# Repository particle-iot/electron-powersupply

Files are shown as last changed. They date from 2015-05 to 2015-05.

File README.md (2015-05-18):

Electron Power Management
---
[Place to host the experimental power supply design files for the Electron]

> To put it simply, the challenge in designing the power supply unit for the Electron is _supply and demand_. 

A cellular module is a power hungry device. Unlike WiFi, a GSM module requires a higher burst of power during transmission. These power/current spikes can go as high as 2Amps. This clearly exceeds USB's limit of 500mA in most cases. When developing on the Electron connected to a computer, care must be taken not to exceed the USB's limit while maintaining uninterrupted power to the cellular module. Most portable devices overcome this by having a battery connected at all times, like mobile phones. For a device like the Electron, it becomes essential to have the flexibility to power it either via the USB, battery or both.

The USB powered GSM modems currently available in the market use a switch-mode DC regulator with a high capacity bulk capacitor at the output. This capacitor stores enough energy to power the GSM module during its peak power requirements. At the same time, the regulator makes sure not to exceed the 500mA limit of draw current from a USB port. Most of the USB ports on today's computers are capable of sourcing 1Amp of continuous current. This allows for the use of a smaller bulk capacitor, but you still need to use one.

Things get a little interesting when you consider that 2G and 3G power requirements are completely different. The main difference is that a 2G TX burst will consume upto 2Amp of peak current, while in 3G burst is more controllable and flat with a peak requirement of 0.8A.

**Potential setup for the power unit:**

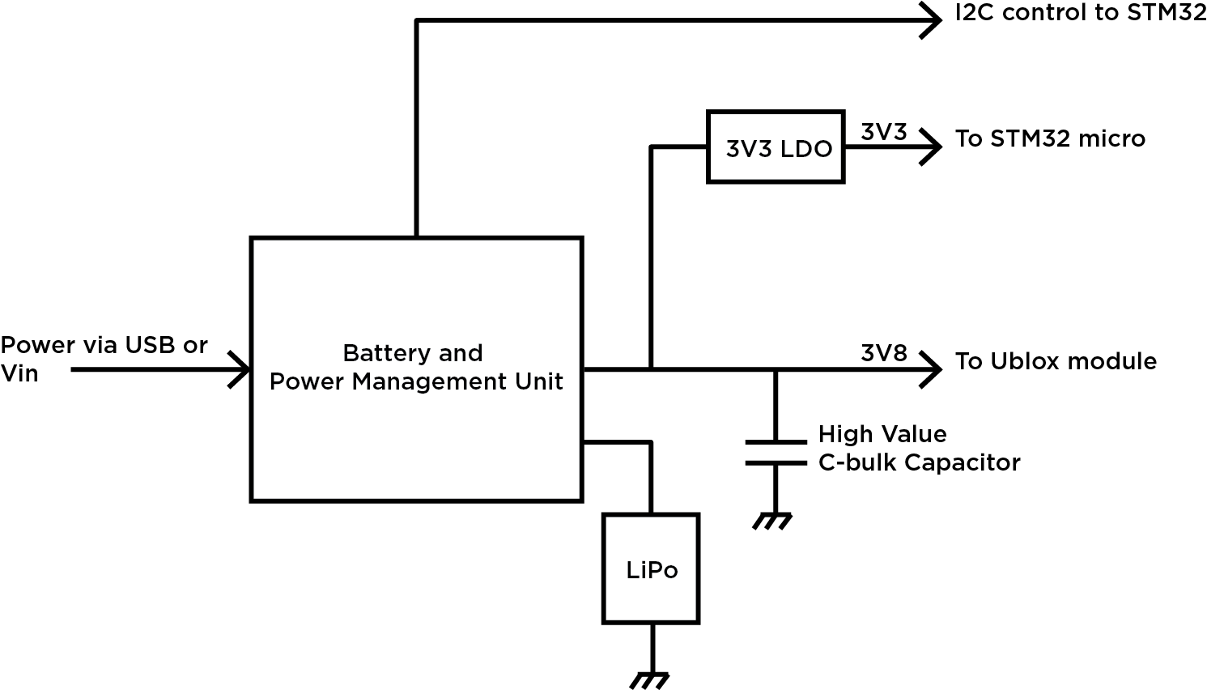
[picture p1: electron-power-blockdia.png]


**Requirements for the PMC:**
 - Programmable input current limit
 - Built-in charger for 3.7V LiPo
 - Ouput current of minimum 1A
 - Power path management (optional)
 - Build-in switcher (optional)
 - Small footprint

**List of ICs under evaluation:**
- [BQ24298] (http://www.ti.com/lit/ds/symlink/bq24298.pdf) complete PMC from TI
- [LTC3567] (http://cds.linear.com/docs/en/datasheet/3567f.pdf) compete PMC from LT
- [BQ24030] (http://www.ti.com/lit/ds/symlink/bq24030.pdf) complete PMC - currently used on the power shield
- [TPS62750] (http://www.ti.com/lit/ds/symlink/tps62750.pdf) only a regulator

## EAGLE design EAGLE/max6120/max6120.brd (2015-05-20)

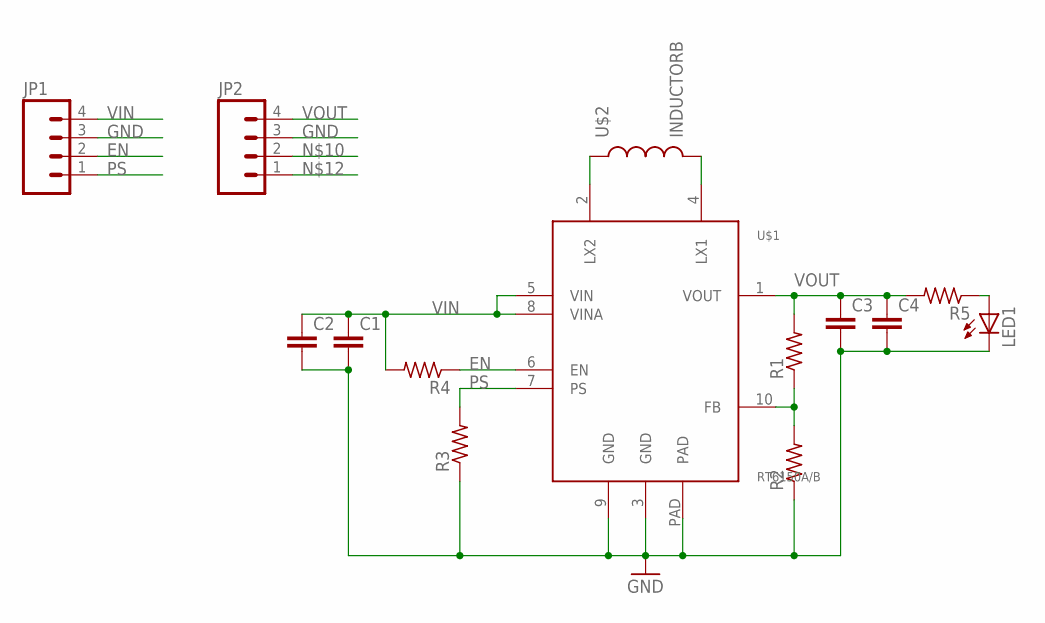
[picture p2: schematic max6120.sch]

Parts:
C1, C2, C3, C4: C-EUC0603; C0603
JP1, JP2: M041X04_NO_SILK; 1X04_NO_SILK
LED1: LEDCHIP-LED0603; CHIP-LED0603
R1, R2, R3, R4, R5: R-US_R0402; R0402
U$1: RT6150A/B; DFN3X310L
U$2: INDUCTORB; INDUCTOR-NR3015

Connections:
EN: JP1.2, R4.1, U$1.6 (EN)
GND: C1.2, C2.2, C3.2, C4.2, JP1.3, JP2.3, LED1.C, R2.1, R3.1, U$1.3 (GND), U$1.9 (GND), U$1.PAD
unnamed: U$1.2 (LX2), U$2.1
unnamed: U$1.4 (LX1), U$2.2
unnamed: R1.1, R2.2, U$1.10 (FB)
unnamed: LED1.A, R5.1
PS: JP1.1, R3.2, U$1.7 (PS)
VIN: C1.1, C2.1, JP1.4, R4.2, U$1.5 (VIN), U$1.8 (VINA)
VOUT: C3.1, C4.1, JP2.4, R1.2, R5.2, U$1.1 (VOUT)

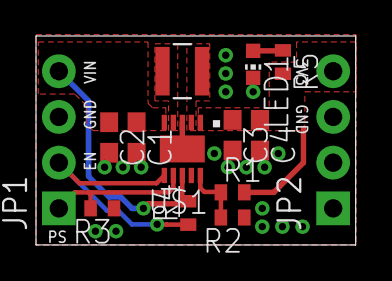
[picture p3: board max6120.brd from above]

Board: 2 copper layers, 17.8 x 11.6 mm, 15 parts (0 on the bottom side), 9 nets.

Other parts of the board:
U$3: SPARK_LOGO2

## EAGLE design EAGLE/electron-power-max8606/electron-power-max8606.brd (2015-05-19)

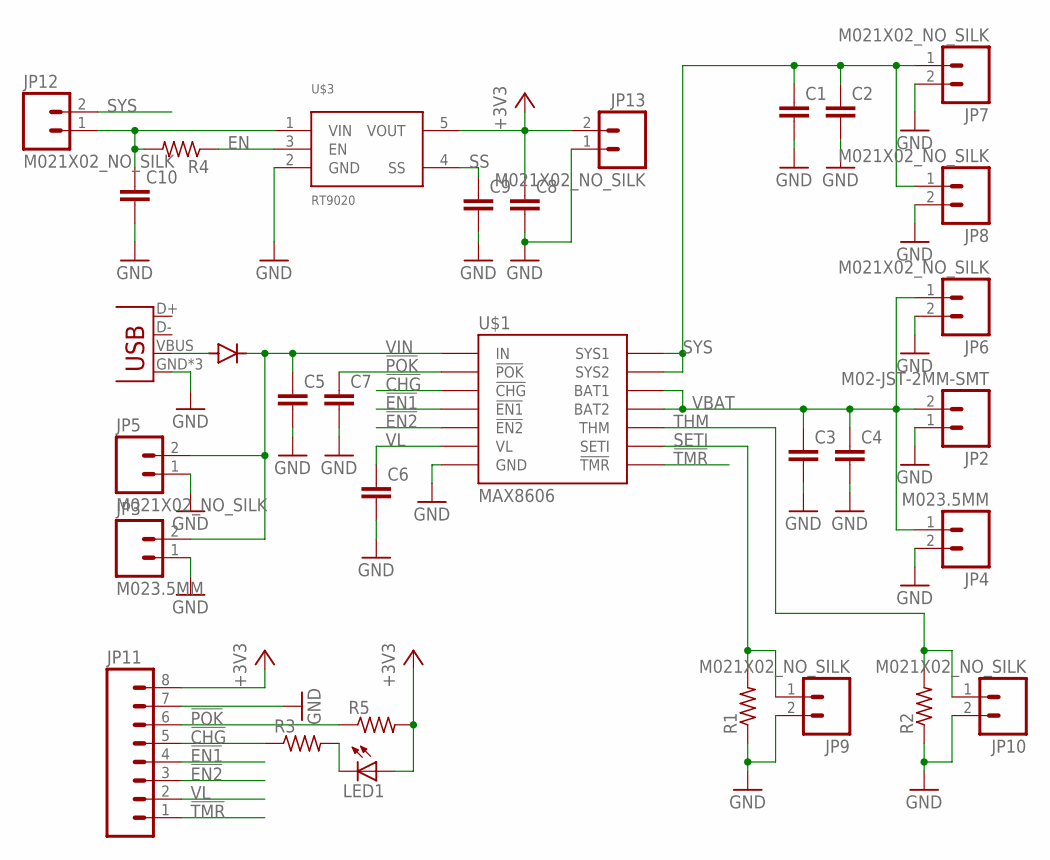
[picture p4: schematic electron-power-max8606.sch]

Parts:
C1, C2, C3, C4, C5: C-EUC0805; C0805
C6, C7, C8, C9, C10: C-EUC0402; C0402
JP1: USBUSB-MICROB-SLOT-HOLE; USB-MICROB-SLOT-HOLE
JP2: M02-JST-2MM-SMT; JST-2-SMD
JP3, JP4: M023.5MM; SCREWTERMINAL-3.5MM-2
JP5, JP6, JP7, JP8, JP9, JP10, JP12, JP13: M021X02_NO_SILK; 1X02_NO_SILK
JP11: M08; 1X08_PIN1_NO_SILK
LED1: LEDSML0805; SML0805
R1, R2, R3, R4, R5: R-US_R0402; R0402
U$1: MAX8606; TDFN-14
U$2: DIODE; DIODE-DO-220AA(SMP)
U$3: RT9020; SOT23-5

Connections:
!CHG: JP11.5, R3.1, U$1.P$6 (!CHG)
!EN1: JP11.4, U$1.P$10 (!EN1)
!EN2: JP11.3, U$1.P$9 (!EN2)
!POK: C7.1, JP11.6, R5.1, U$1.P$7 (!POK)
!TMR: JP11.1, U$1.P$8 (!TMR)
+3V3: C8.1, JP11.8, JP13.2, LED1.A, R5.2, U$3.5 (VOUT)
EN: R4.1, U$3.3 (EN)
GND: C1.2, C2.2, C3.2, C4.2, C5.2, C6.2, C7.2, C8.2, C9.2, C10.2, JP1.GND, JP1.MT1 (GND), JP1.MT2 (GND), JP2.1 (2), JP3.1, JP4.2, JP5.1, JP6.2, JP7.2, JP8.2, JP9.2, JP10.2, JP11.7, JP13.1, R1.1, R2.1, U$1.P$11 (GND), U$3.2 (GND)
unnamed: JP1.VBUS, U$2.ANODE
unnamed: C10.1, JP12.1, R4.2, U$3.1 (VIN)
unnamed: LED1.C, R3.2
SETI: JP9.1, R1.2, U$1.P$12 (SETI)
SS: C9.1, U$3.4 (SS)
SYS: C1.1, C2.1, JP7.1, JP8.1, JP12.2, U$1.P$13 (SYS1), U$1.P$14 (SYS2)
THM: JP10.1, R2.2, U$1.P$5 (THM)
VBAT: C3.1, C4.1, JP2.2 (1), JP4.1, JP6.1, U$1.P$1 (BAT1), U$1.P$2 (BAT2)
VIN: C5.1, JP3.2, JP5.2, U$1.P$3 (IN), U$2.CATHODE
VL: C6.1, JP11.2, U$1.P$4 (VL)

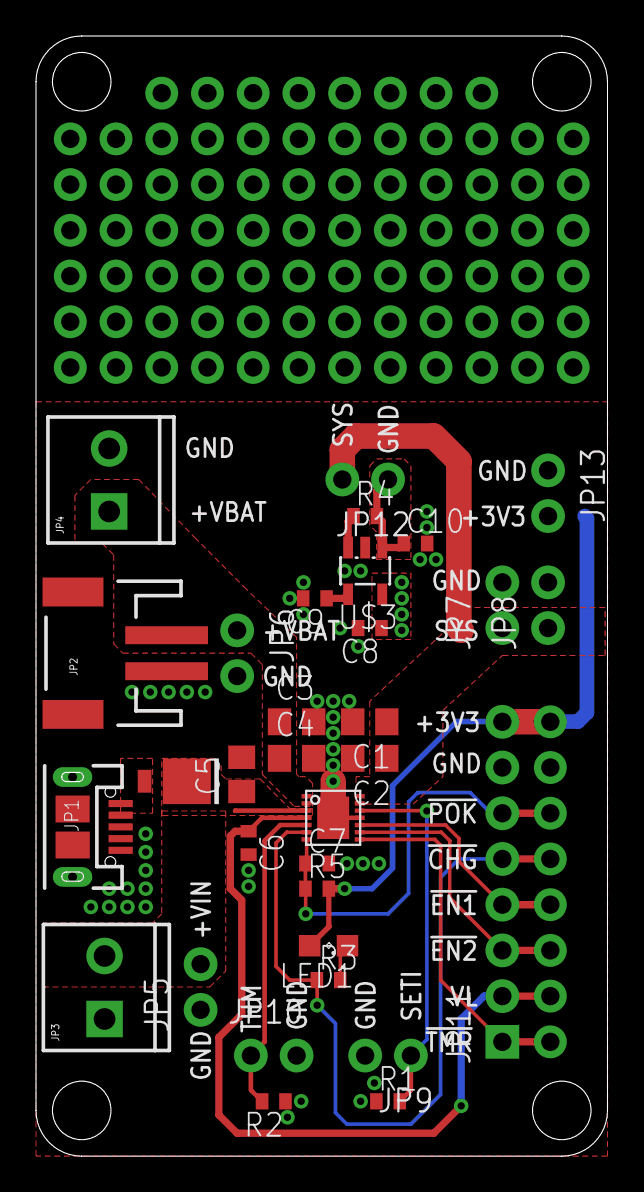
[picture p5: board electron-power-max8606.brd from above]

Board: 2 copper layers, 31.8 x 62.2 mm, 32 parts (0 on the bottom side), 18 nets.

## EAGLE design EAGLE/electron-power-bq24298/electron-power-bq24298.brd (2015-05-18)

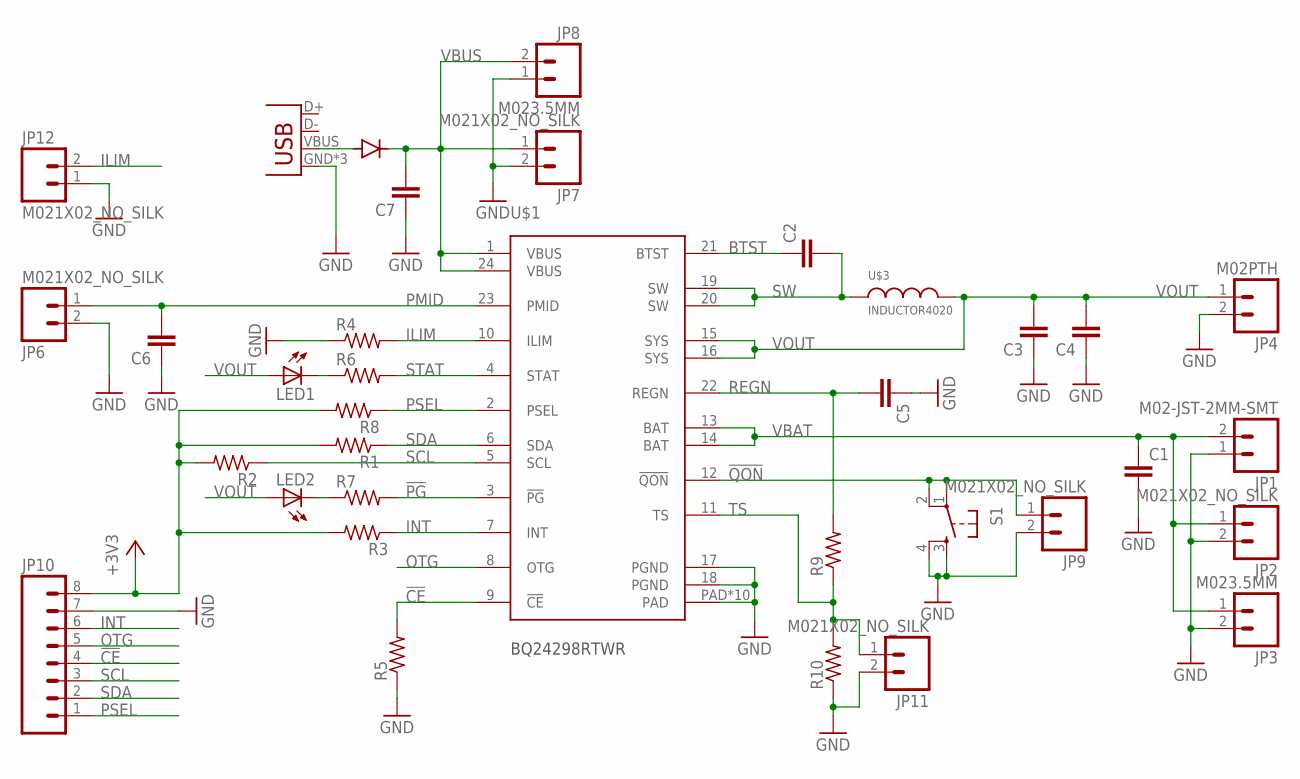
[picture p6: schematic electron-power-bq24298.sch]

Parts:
C1, C3, C4, C6, C7: C-EUC0805; C0805
C2, C5: C-EUC0402; C0402
JP1: M02-JST-2MM-SMT; JST-2-SMD
JP2, JP6, JP7, JP9, JP11, JP12: M021X02_NO_SILK; 1X02_NO_SILK
JP3, JP8: M023.5MM; SCREWTERMINAL-3.5MM-2
JP4: M02PTH; 1X02
JP5: USBUSB-MICROB-SLOT-HOLE; USB-MICROB-SLOT-HOLE
JP10: M08NO_SILK; 1X08_NO_SILK
LED1, LED2: LEDSML0805; SML0805
R1, R2, R3, R4, R5, R6, R7, R8, R9, R10: R-US_R0402; R0402
S1: TAC_SWITCHSMD; TACTILE_SWITCH_SMD
U$1: BQ24298RTWR; QFN24
U$2: DIODE; DIODE-DO-220AA(SMP)
U$3: INDUCTOR4020; 4020TYPE

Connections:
!CE: JP10.4, R5.2, U$1.9 (!CE)
!PG: R7.2, U$1.3 (!PG)
!QON: JP9.1, S1.1, S1.2, U$1.12 (!QON)
+3V3: JP10.8, R1.2, R2.2, R3.2, R8.2
BTST: C2.1, U$1.21 (BTST)
GND: C1.2, C3.1, C4.1, C5.1, C6.1, C7.1, JP1.1 (2), JP2.2, JP3.2, JP4.2, JP5.GND, JP5.MT1 (GND), JP5.MT2 (GND), JP6.2, JP7.2, JP8.1, JP9.2, JP10.7, JP11.2, JP12.1, R4.1, R5.1, R10.1, S1.3, S1.4, U$1.17 (PGND), U$1.18 (PGND), U$1.PAD, U$1.PAD@1 (PAD), U$1.PAD@2 (PAD), U$1.PAD@3 (PAD), U$1.PAD@4 (PAD), U$1.PAD@5 (PAD), U$1.PAD@6 (PAD), U$1.PAD@7 (PAD), U$1.PAD@8 (PAD), U$1.PAD@9 (PAD)
ILIM: JP12.2, R4.2, U$1.10 (ILIM)
INT: JP10.6, R3.1, U$1.7 (INT)
unnamed: JP5.VBUS, U$2.ANODE
unnamed: LED1.C, R6.1
unnamed: LED2.C, R7.1
OTG: JP10.5, U$1.8 (OTG)
PMID: C6.2, JP6.1, U$1.23 (PMID)
PSEL: JP10.1, R8.1, U$1.2 (PSEL)
REGN: C5.2, R9.2, U$1.22 (REGN)
SCL: JP10.3, R2.1, U$1.5 (SCL)
SDA: JP10.2, R1.1, U$1.6 (SDA)
STAT: R6.2, U$1.4 (STAT)
SW: C2.2, U$1.19 (SW), U$1.20 (SW), U$3.P$1 (1)
TS: JP11.1, R9.1, R10.2, U$1.11 (TS)
VBAT: C1.1, JP1.2 (1), JP2.1, JP3.1, U$1.13 (BAT), U$1.14 (BAT)
VBUS: C7.2, JP7.1, JP8.2, U$1.1 (VBUS), U$1.24 (VBUS), U$2.CATHODE
VOUT: C3.2, C4.2, JP4.1, LED1.A, LED2.A, U$1.15 (SYS), U$1.16 (SYS), U$3.P$2 (2)

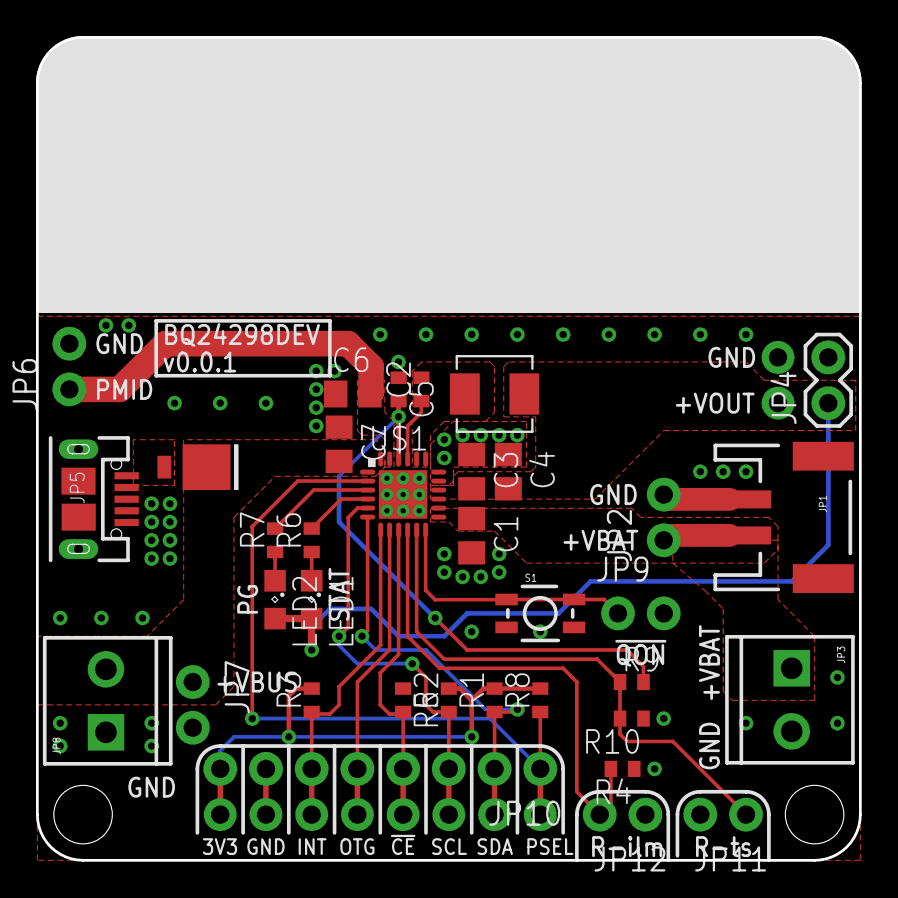
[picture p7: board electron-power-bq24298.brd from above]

Board: 2 copper layers, 45.7 x 45.7 mm, 35 parts (0 on the bottom side), 23 nets.

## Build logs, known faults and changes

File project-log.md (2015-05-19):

Electron Power - project log
---

**May 19, 2015:**
Maker Faire 2015 was amazing! We are now [Particle!](http://blog.particle.io/2015/05/13/spark-is-now-particle/)

During the craziness of this event, I was still able to make some progress in the Electron domain. There are now two power supply test boards routed up and ready for the fab house. The BQ24298 was mentioned in the previous update, the new one is based around the Maxim MAX8606 which seems to be more widely available compared to the TI variant. I have also included a 3V3 LDO from Richtek, RT9020-33GB, for powering up the microcontroller. 

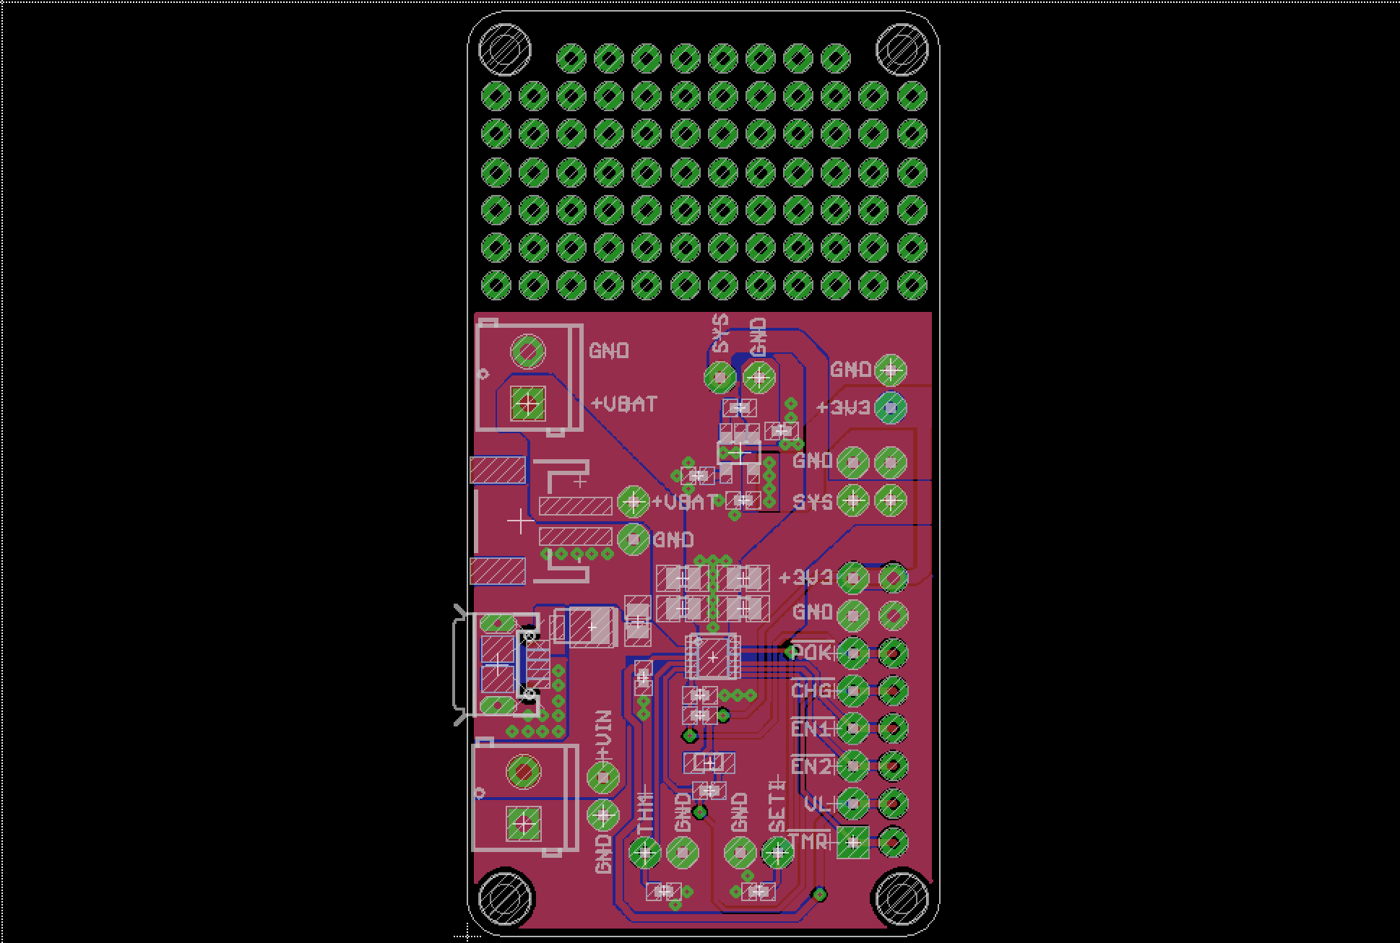
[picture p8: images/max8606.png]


We are currently looking into a few 3V3 regulators that will power the micro in the second stage. 

LDO:
- RT9020
- TPS735
- MAX8902

Buck-Boost:
- TPS63031
- TPS63051
- RT6150A/B 

**May 6, 2015:**

Designed the PCB for testing the BQ24298 today. I left enough proto area for me to add a buck-boost regulator on this board later when I get to it.

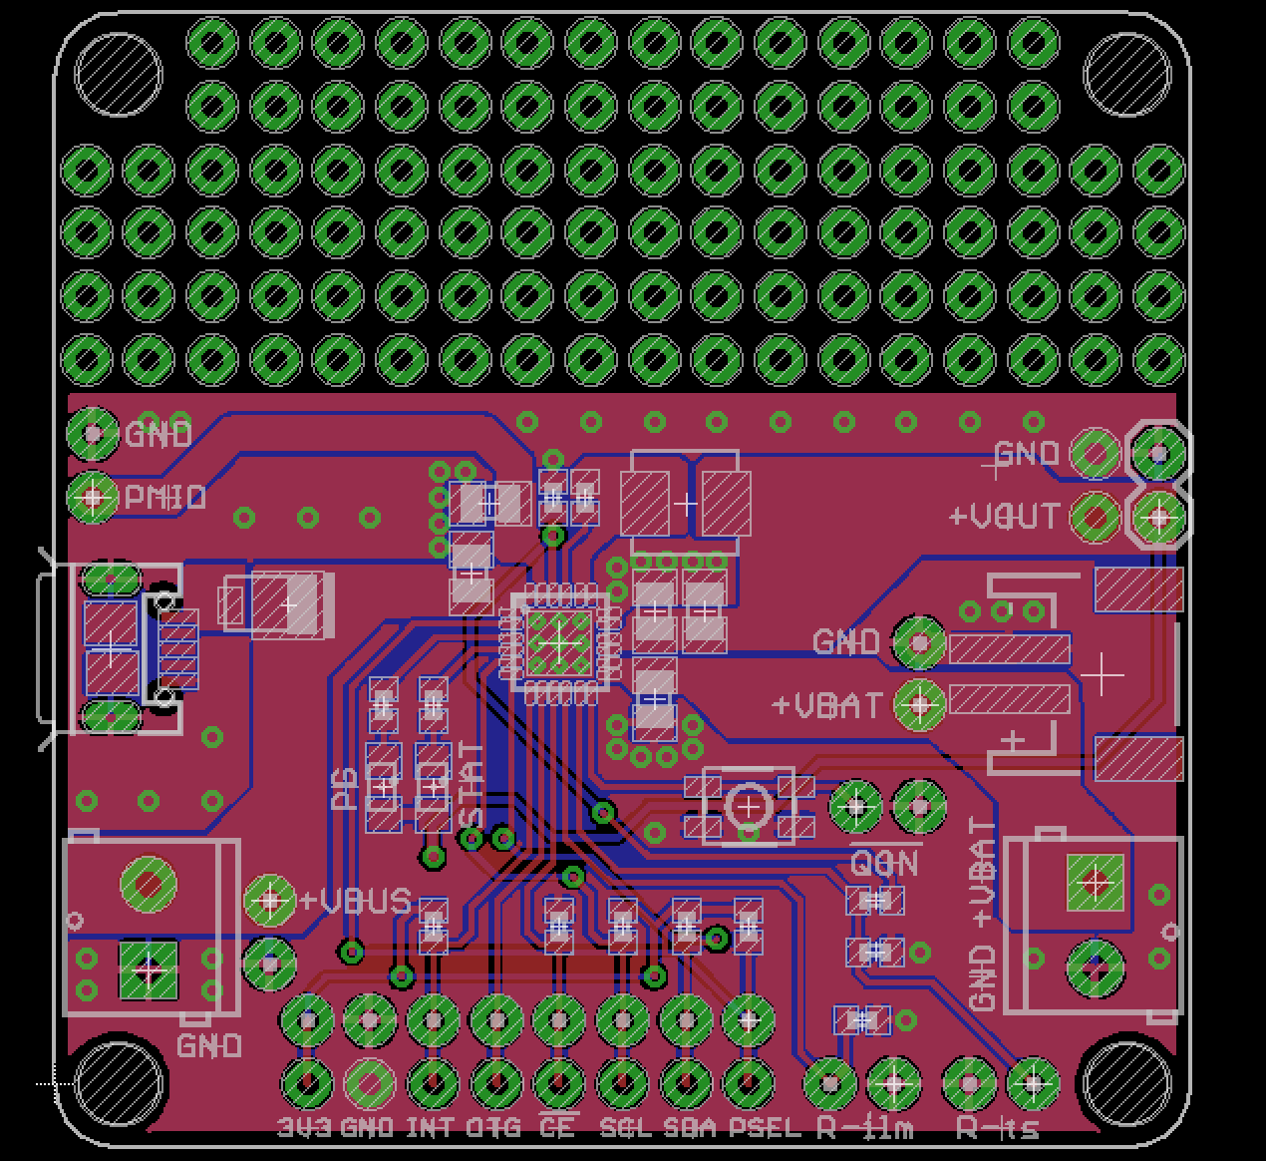
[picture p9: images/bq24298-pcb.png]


**May 6, 2015:**

I'm currently using the TI's BQ24298 as the PMC and leaving the option open to add an LDO or a buck-boost regulator to power the STM32 micro from it. There are some very good options out there for high efficiency regulators. The cellular module can be directly powered from the Vout of the BQ24298 chip since it's within the safe limits (3.5V to 4.35V).

I received some parts I ordered over digikey to breadboard a mock-up of the ublox power consumption under different loads.

>In another news, SpaceX pad abort test was a [success today!!](http://www.spacex.com/news/2015/05/06/crew-dragon-completes-pad-abort-test)

**May 5, 2015:**

The LTC3567 seemed like a lead candidate but it will still require one addional part to bring down the Vout below its max of 4.7V before powering the GSM module. This is a good part since it has a built-in 3V3 switching regulator, but the total cost of the system is signifcantly higher than the TI option.

**Setup 1:**

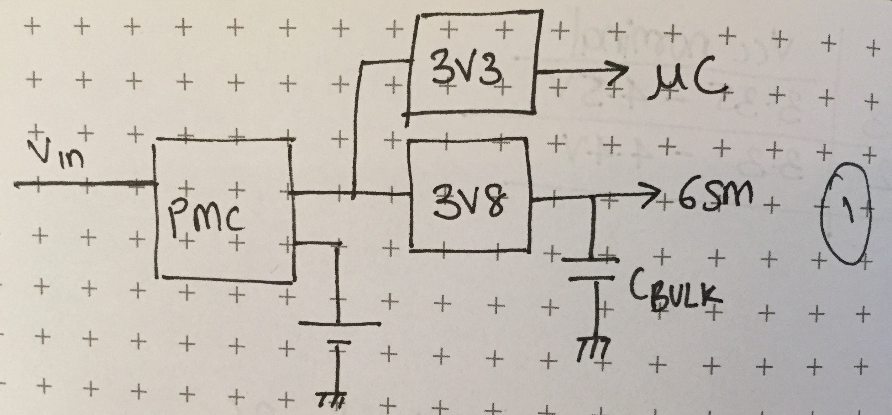
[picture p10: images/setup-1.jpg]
setup 1

---
**Setup 2:**

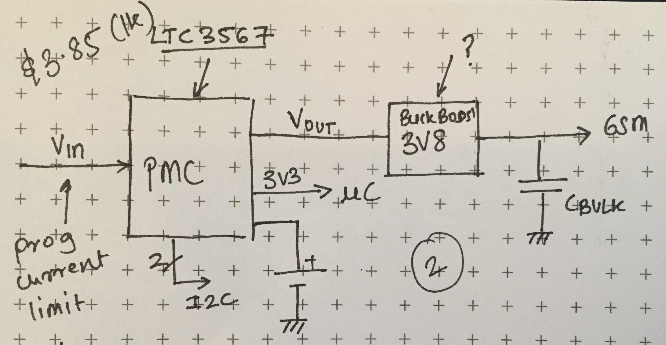
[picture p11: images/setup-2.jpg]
setup 2

---
**Setup 3:**

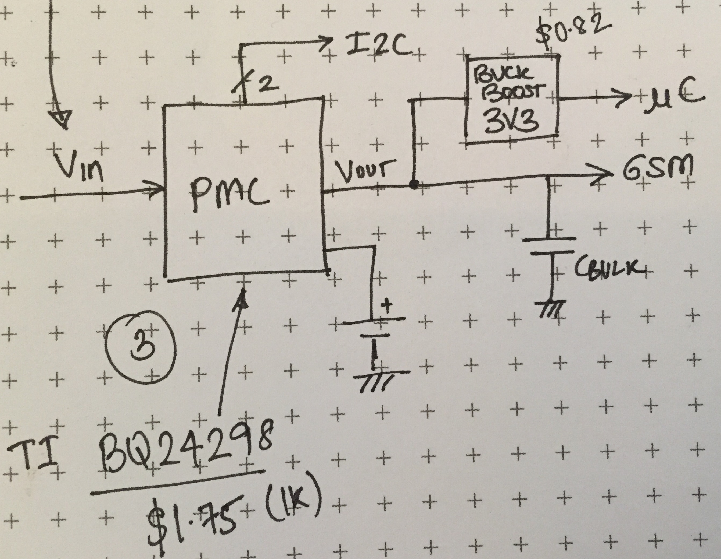
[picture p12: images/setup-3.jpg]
setup 3


I've started designing a board around the TI's BQ24298 chip.

**May 4, 2015:**  
*May the 4th be with you.*  

Identified the minimum requirements for the PMC.
 - Programmable input current limit
 - Built-in charger for 3.7V LiPo
 - Output current of minimum 1A
 - Power path management
 - Build-in switcher (optional)
 - Small footprint

Identified potential parts:
 - BQ24298 complete PMC from TI (ordered an eval board)
 - LTC3567 compete PMC from LT (have an eval board)
 - BQ24030 complete PMC - currently used on the power shield (have an eval board)
 - TPS62750 only a regulator - (have an eval board)  
 
 Ordered parts for building a mock up dummy load to simulate the power requirements of the GSM module. Its essentially a MOSFET with a high wattage load resistor.

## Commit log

2015-05-18 added eagle files and ref docs
    [electron-power-bq24298.brd, electron-power-bq24298.sch, electron-power-max8606.brd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]
2015-05-19 added pin labels
    [electron-power-max8606.brd]
2015-05-19 generated gerber files
    [electron-power-max8606.GBL, electron-power-max8606.GBO, electron-power-max8606.GBS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]
2015-05-19 gernerated gerbers for bq24298
    [electron-power-bq24298.GBL, electron-power-bq24298.GBO, electron-power-bq24298.GBS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]
2015-05-20 added max6120 based buck-boost board design and gerbers
    This is an evaluation breakout board based on the maxim MAX6120
    buck-boost regulator.
    [max6120.brd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]

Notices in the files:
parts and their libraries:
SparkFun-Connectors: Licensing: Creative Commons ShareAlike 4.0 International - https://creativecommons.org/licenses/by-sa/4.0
